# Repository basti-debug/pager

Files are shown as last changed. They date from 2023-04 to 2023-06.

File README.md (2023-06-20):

# pager
A Project which uses LORA Modules to communicate messages over long distances and has simple inputs with buttons and menus. There is also a bluetooth powered companion app for Windows 11

---

This project is not completed, many more features would be possible see:
[not completed features](https://github.com/users/basti-debug/projects/3)

---

Please also visit our wiki for more questions:
[wiki](https://github.com/basti-debug/pager/wiki)



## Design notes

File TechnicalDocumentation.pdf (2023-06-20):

HWE-Übungen 4CHEL | SS 2022-23

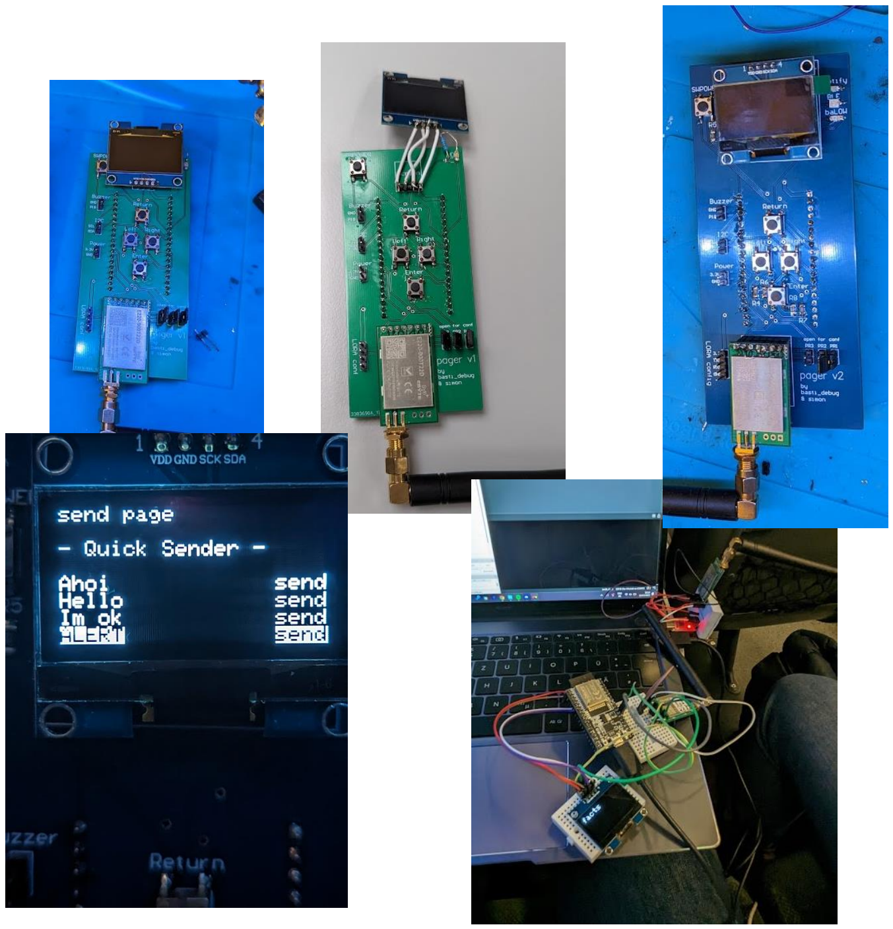
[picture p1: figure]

Pager-Doku-Koller-Mayrhofer | Seite 1 von 9

## Projekt: LoRa - Handlicher Pager

Name Schüler: | Koller Simon, Mayrhofer Sebastian
Betreuer: | Prof. Jena
HTL Rankweil | 4CHEL | Schuljahr 2022-23

Aufgabenbeschreibung:
Aus 2 LoRa Modulen soll ein Projekt unserer Wahl realisiert werden. Es handelt sich dabei um LoRa Module der e220-er Reihe von eByte. Die Kommunikation mit den Modulen verläuft seriell über UART. Die einzige Vorgabe, die wir einzuhalten haben, ist, dass eine Datenübertragung über die LoRa Module im Mittelpunkt des Projektes steht.

Zielsetzung:
Wir haben uns vorgenommen mithilfe der LoRa Module zwei handliche Pager zu realisieren. Dafür wollen wir ein ESP32 DevModule, Screens und Knöpfe verwenden. Als Ziel setzen wir uns mithilfe der Knöpfe zwischen Menüs hin und her zu wechseln und vorgefertigte Nachrichten zu schicken. Das Ganze soll kabellos sein, also Batterie-betrieben. Dennoch wollen wir auch individuelle Nachrichten mittels Laptop oder Handy schicken, damit die Möglichkeiten nicht begrenzt sind. Damit dies immer noch kabellos möglich ist, nehmen wir uns vor den Pager auch über Bluetooth steuerbar zu machen.

Inhaltsverzeichnis:

Liste Entwicklungstools:
Microsoft Word: Version 2210 Greenshot: Version 1.2.10
Altium Designer: Version 23.3.1 Arduino IDE: Version 2.1.0
Git
eByte E220 LoRa Konfigurationstool

Grundkonzept:

Funktionalität:
Schnellnachrichten zwischen den Pagern über Menüs senden oder individuelle Nachrichten über angeschlossene Geräte (z.B. Laptop). Für kurze Strecken können Nachrichten über Bluetooth zwischen Laptop und Pager ausgetauscht werden. Bluetooth kann am Pager im Einstellungsmenü ein- bzw. ausgeschalten werden und der Pager kann vor anderen Bluetooth-Geräten versteckt werden.

Blockdiagramme:

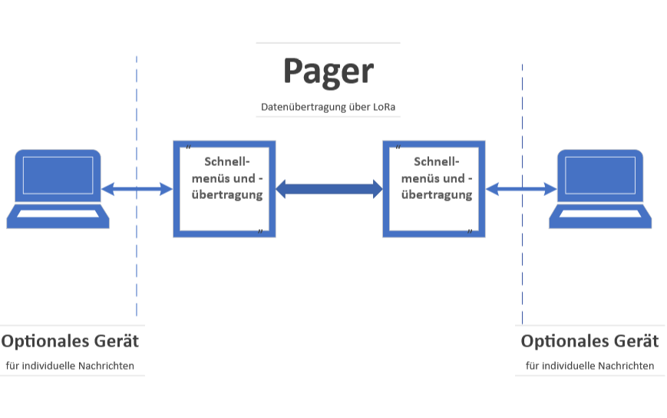
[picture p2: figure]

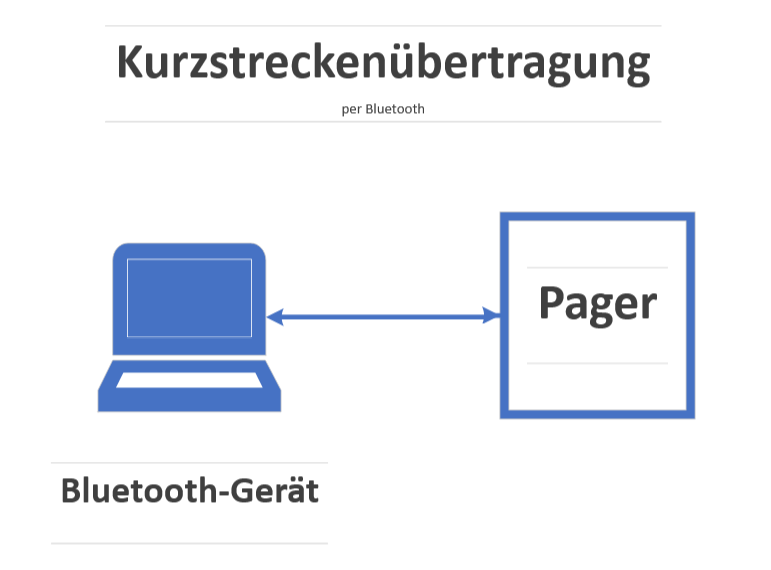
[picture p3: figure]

Technische Realisierung:

LoRa-Modul:

Einführung:
LoRa … Long Range

Als LoRa wird die von Semtech hergestellte Low-Power-Wide-Area-Network-Technology (LPWAN) bezeichnet.

Die großen Vorteile von LoRa sind bereits im Namen ersichtlich: große Reichweite und geringer Energieverbrauch.

Zur Signalübertragung verwendet LoRa die Chirp-Spread-Spectrum-Technologie (CSS). CSS kombiniert 2 Aspekte der Informationstechnik:

- Chirps:
- Spread-Spectrum:

Chirps beschreiben Signale mit zeitlichen Frequenzänderungen, während Spread-Spectrum ein Verfahren ist, bei dem ein Signal gezielt umgewandelt wird, um eine größere Bandbreite und ein breiteres Frequenzspektrum zu nutzen.

Vorteile:

- Geringere Störanfälligkeit
- Hohe Datensicherheit
- Erschwert dritten, übertragene Daten auszulesen

Einstellmöglichkeiten:
Mit der Software von eByte (s.o.) kann das LoRa Modul konfiguriert werden:

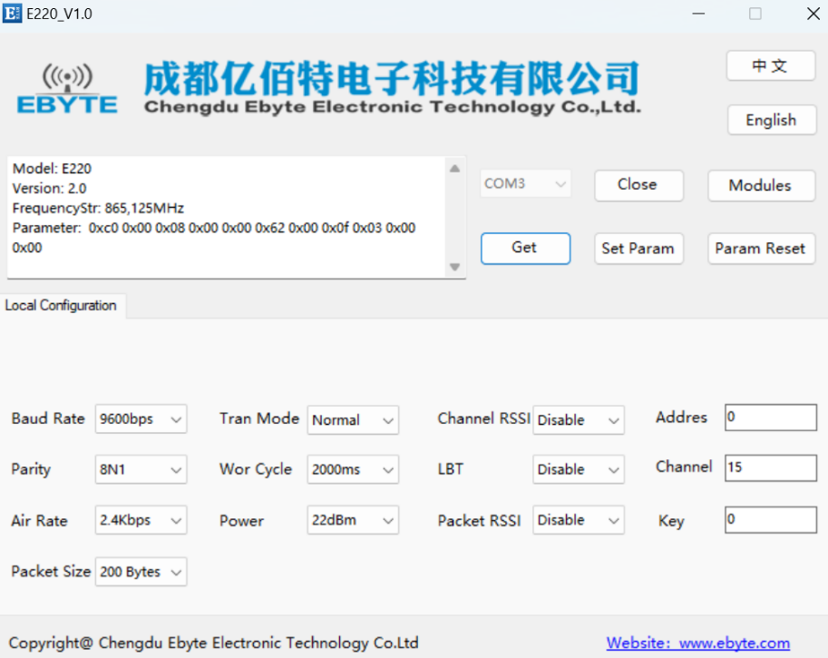
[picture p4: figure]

Die wichtigsten Parameter dabei sind Baud Rate, „Addres“ und Channel. Damit zwei oder mehrere LoRa-Module miteinander kommunizieren können, ist es wichtig, dass diese auf dieselbe Adresse und denselben Channel konfiguriert werden. Die Baud Rate von 9600bps haben wir gewählt damit wir auch einfach mit Terminal Programmen arbeiten können. Die restlichen Parameter können auf den
Standardeinstellungen gelassen werden.

GUI:
Wir verwenden das 1,3 Zoll I2C Display von AZ-Delivery mit einer Auflösung von 128 X 64 Pixel. Der Bildschirm dient als Benutzeroberfläche für den Pager. Hier kann der Benutzer die zuvor empfangenen Nachrichten oder die aktuellen Einstellungen ansehen. Außerdem kann er vorgefertigte Schnellnachrichten auswählen und verschicken. Das Ganze kann in 3 Schnellmenüs erreicht werden:
- Home-Page
- Send page
- Connection settings

Home-Page:
Bild und Beschreibung einfügen.

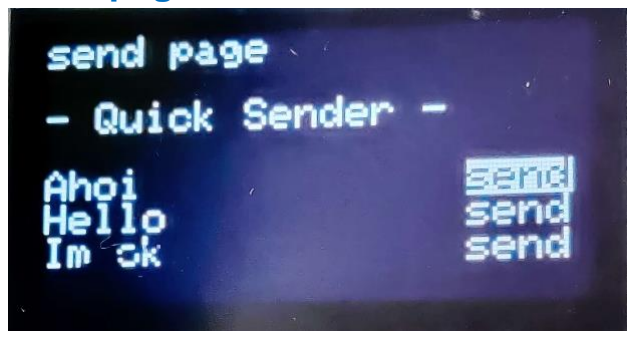
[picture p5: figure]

Send page:
Auf der send-Seite können die Schnellnachrichten ausgewählt und über LoRa versendet werden. Es besteht eine programmierbare Auswahl an Schnellnachrichten.

(Bild: 3 Schnellnachrichten „Ahoi“, „Hello“, „Im ok“. Ersteres ist ausgewählt)

Connection settings:
Hier können Bluetooth-Einstellungen vom Pager verändert werden. Zum einen kann Bluetooth ein- bzw. ausgeschalten werden. Und es kann eingestellt werden, ob der Pager von anderen Bluetooth-Geräten erkannt werden kann.

Außerdem wird in der Info-Anzeige in der unteren Hälfte des Displays der Bluetooth-Name und der Status angezeigt.

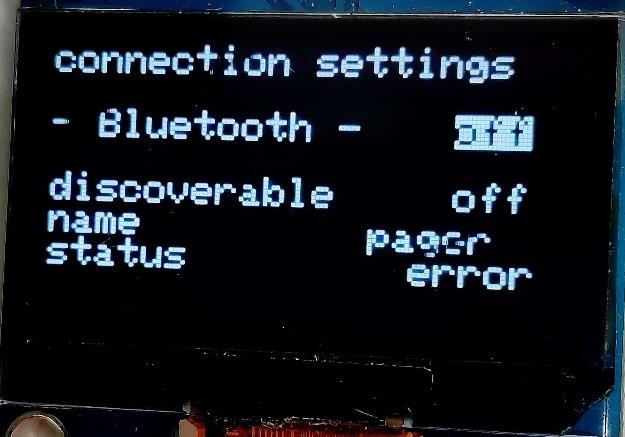
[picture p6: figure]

(Bild: Status = error, weil noch nicht zu Gänze ausprogrammiert).

Erweiterte Anzeigeelemente:
Auf der rechten Seite des Displays gibt es 3 Leds:
- die erste, die Notification LED, war eigentlich vorgesehen, dass diese blinkt sobald eine neue Nachricht ankommt doch wir hatten leider Pins ohne Ausgangstreiber des ESPs geroutet und nun haben wir keinen Pin mehr übrig -> Funktion nicht implementiert
- die zweite, die BLE LED, leuchtet sobald Bluetooth aktiviert ist
- die dritte, die baLOW LED, war anfangs als Batterie Alarm vorgesehen, doch da wir die Batterie direkt in unseren Circuit einspeisen und kein BMS dazwischen ist, können wir nicht herausfinden ob die Batterie voll oder leer ist, wir wissen nur dass sie leer ist wenn der ESP abstürzt -> Daher haben wir diese als ALERT (Alarm) LED umfunktioniert, sie soll nun den Nutzer, zusammen mit dem Buzzer auf eine wichtige Nachricht hinweisen.

Bedienelemente:
Die Menüs werden über 5 Taster bedient. Mit den Taster „Left“ und „Right“ kann zwischen den Menüs gewechselt werden. In welche Richtung ist dabei selbsterklärend. Mit dem unteren Taster („Return“) kann gescrollt werden. Und mit „Enter“ wird die jeweilige Aktion ausgeführt. Z.B.: Bluetooth einschalten oder Schnellnachricht versenden.

Mit dem Taster SWPower können empfangene Nachrichten nach dem Lesen „gelöscht“ werden. Das heißt, die Nachrichten werden aus der Anzeige auf der Home-Page entfernt. Ebenfalls wird durch den SWPOWER eine anstehende Alarm Meldung quittiert.

Akustische Empfangssignalisierung:
Damit Nutzer des Pagers auch auf jeden Fall bemerken, dass sie eine Nachricht empfangen haben, haben wir zusätzlich zur LED, eine akustische Signalisierung über einen Piezo-Buzzer eingebunden. Bei Empfang eines Alarms, der im Quick Send Menu vorhanden ist, wird eine kleine Melodie abgespielt.

Piezo-Buzzer:
Piezo-Buzzer oder Summer basieren auf dem physikalischen Prinzip des inversen Piezo-Effekts. Dabei werden an elektrisch neutralen Kristallen (z.B. Siliziumdioxid SiO2) Spannungen angelegt. Diese angelegten Spannungen sorgen dafür, dass sich der Kristall verformt und so mechanische Schwingungen ausführt. Spannung und mechanische Schwingung sind dabei direkt proportional.

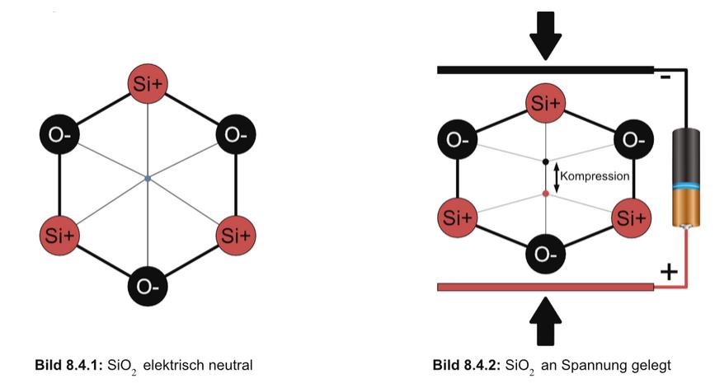
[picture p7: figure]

Schaltet man nun die Spannung mit unterschiedlichen Frequenzen ein und aus entstehen daraus Töne.

Desktop Applikation:
Damit bei der erweiterten Bedienung des Pagers über einen Laptop oder PC keine nervtötende Terminal-Programme und Converter benötigt werden, haben wir eine Steuerung des Pagers über eine Desktop-Applikation kreiert.

Mit dieser ist es Möglich benachrichtigt zu werden wenn eine Nachricht auf dem über Bluetooth verbundenem Pager eingetroffen ist. Ebenfalls war vorgesehen das man die Quick Send Nachrichten abändern kann und z.B. den Namen des Gerätes ändern kann. Dies wurde jedoch aufgrund Zeitlichen Mangels nicht vollständig umgesetzt.

ESP32:
Der ESP32 ist das Herzstück des Pagers. Er verbindet alle Module und steuert diese an. (LoRa, Bildschirm, Taster, Buzzer, LEDs). Wie verwenden das vorgefertigte ESP32 Wrover Module. Features und Funktionalität des Moduls können in dessen Dokumentation nachgelesen werden (siehe Literaturnachweise).

LoRa-Ansteuerung:
Das LoRa Modul benötigt eine Ansteuerung über UART. Die UART-Konfiguration ist dabei, von der vorherigen LoRa-Konfiguration abhängig. Bei uns also 8N1 und eine Baud-Rate von 9600bps.

(UART Dokumentation -> Literaturnachweise)

Screen-Ansteuerung:
Der 1,3“ Screen wird über IIC, mit Hilfe der „Adafruit_GFX“ und der „Adafruit_SH110X“ Library angesteuert.

Ablauf der Erstellung:
Wir starteten mit einem Testaufbau der aus einem LORA Modul und einem UART Converter bestand und einem LORA Modul mit einem ESP. Dieser Testaufbau wurde von uns am Längsten benutzt um die Grundlagen der LORA Module kennenzulernen und die Basis des Codes zu schreiben.

Nach der Fertigstellung der Grundlagen haben wir mit dem Design eines ersten Prototypen gestartet, wobei uns nach kurzem Testen gleich einige Fehler im Design aufgefallen sind, wir hatten ein sehr starkes Tasterprellen, welches durch die internen PullUps des ESPs entstanden. Wir haben anschließend noch einen Fehler begangen der uns später noch einholte, wir haben die Bauteile nicht gesocketed sondern direkt drauf gelötet.

Nach dem wir mit der ersten Version des Boards die Software des Pagers schrieben, haben wir eine zweite Version erstellt in welcher wir unsere Fehler ausglichen.

Gegen Ende finalisierten wir die Software des Pagers selbst und starteten mit der Bluetooth implementation und der Windows Software

Probleme:

LORA Konfiguration
Aufgrund der schlechten Dokumentation unseres LORA Bausteines wussten wir Anfangs nicht wie wir das Board ansteuern sollen oder wie wir den Baustein konfigurieren sollen. Es dauerte einige Zeit bis wir die richtigen Einstellungen getroffen haben und über LORA Daten senden konnten -> mittlerer Zeitverlust

Screens
Aufgrund des mehrfachen Wechsels der Boards sind uns die Bildschirme eingegangen, wir probierten diese wieder und wieder zu reparieren, doch einer bei einer der beiden Screens war das Backlight defekt, welches wir nicht wieder reparieren konnten.

Bluetooth in WinUI3
Gegen Ende des Projektes als wir mit der Windows App starteten, hatten wir massive Probleme, da es uns Anfangs nicht möglich war die Bluetooth API von Windows korrekt anzusteuern, doch als wir ein externes NuGet nahmen, statt der Windows direkten API, funktionierte der Aufbau der Verbindung, jedoch dauert sie ein wenig länger.

Bedienungsanleitung:
Eine Ausgiebige Bedienungsanleitung, inklusive einer Erklärung der Implementation ist unter https://github.com/basti-debug/pager zu finden Code, Software sind ebenfalls in der Github Repository zu finden

Literaturnachweise:
Piezo-Buzzer

https://edistechlab.com/piezo-summer-buzzer/?v=fa868488740a

ESP32 Wrover

https://cdn-shop.adafruit.com/product-files/3384/esp32-wrover_datasheet_en.pdf

UART

https://www.ti.com/lit/ug/sprugp1/sprugp1.pdf?ts=1686988071833&ref_url=https%253A%252F %252Fwww.google.gr%252F (https://www.ti.com/lit/ug/sprugp1/sprugp1.pdf?ts=1686988071833)

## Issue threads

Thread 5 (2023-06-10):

code arduino

basti-debug, 2023-06-10:
- [x] Connection menu (add bluetooth devices)
- [x] main menu
- [x] messages history
- [x] send messages

basti-debug, 2023-06-10:
Done with commit [c74a332](https://github.com/basti-debug/pager/commit/c74a332a60129acd2a4b95ad5af3121f2de137e6)
(Pager Software V4)

basti-debug, 2023-06-10:
```c++
// Send Page
void sendpage(int cursor){
  display.clearDisplay();

  display.setTextSize(1);
  display.setTextColor(SH110X_WHITE);
  display.setCursor(0,0);
  display.println("send page");

  display.println("");
  display.println("- Quick Sender -");
  display.println("");
  display.println(msg1);
  display.println(msg2);
  display.println(msg3);

  if(cursor==1){
    //first message
    display.setCursor(100, 32);
    display.setTextColor(SH110X_BLACK, SH110X_WHITE);
    display.print("send");
    //second entry, second msg
    display.setCursor(100,40);
    display.setTextColor(SH110X_WHITE,SH110X_BLACK);
    display.print("send");
    //third entry, thrid msg
    display.setCursor(100,48);
    display.print("send");
  }

  if (cursor == 2){
    //first message
    display.setCursor(100, 32);
    display.print("send");
    //second entry, second msg
    display.setTextColor(SH110X_BLACK, SH110X_WHITE);
    display.setCursor(100,40);
    display.print("send");
    //third entry, thrid msg
    display.setTextColor(SH110X_WHITE,SH110X_BLACK);
    display.setCursor(100,48);
    display.print("send");
  }

  if (cursor == 3){
     //first message
    display.setCursor(100, 32);
    display.print("send");
    //second entry, second msg
    display.setCursor(100,40);
    display.print("send");
    //third entry, thrid msg
    display.setTextColor(SH110X_BLACK, SH110X_WHITE);
    display.setCursor(100,48);
    display.print("send");
    display.setTextColor(SH110X_WHITE,SH110X_BLACK);
  }

  display.display();
}
```

Closed 2023-06-10.

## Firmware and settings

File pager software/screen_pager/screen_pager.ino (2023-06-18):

/*

  Pager Code v4
  by basti_debug

  This is script is in charge of:
*  handling incomming traffic from the module 
*  displaying:
*  * right menu (activate/deactivate bluetooth)
*  * main menu (see latest message)
*  handling user input

* v3 
* Handling Bluetooth Actions 

* v4
* send menu 
* basic sending possible

* v5 
* fixed send menu 
* added Led support

* v6
* bluetooth handling added

*/


// needed Dependencys

#pragma region Dependencys

#include <Wire.h> // IIC 
// Screen
#include <Adafruit_GFX.h>
#include <Adafruit_SH110X.h>

// Bluetooth

#include "BluetoothSerial.h"

#include "Arduino.h"

#pragma endregion

#pragma region Macros
// Screen Address
#define i2c_address 0x3c

// Screen Dimentions
#define screen_width 128
#define screen_height 64

// Initalisation of the Screen with the Adafruit library
#define oled_reset -1
Adafruit_SH1106G display = Adafruit_SH1106G(screen_width, screen_height, &Wire, oled_reset);

// define pins
#define BUZZER_PIN 18
#define RIGHT_PIN 14
#define ENTER_PIN 27
#define LEFT_PIN 25
#define RETURN_PIN 26 
#define POWER_PIN 33

#define bleLED 4
#define notifyLED 12
#define batterylowLED 12

#define NUMFLAKES 10
#define XPOS 0
#define YPOS 1
#define DELTAY 2
#define MAX_DATA_LENGTH 60

#pragma endregion

#pragma region Global Variables

char receivedData[MAX_DATA_LENGTH];
int dataIndex = 0;
int btdataIndex = 0;


// MACROS

// ! you can change this !  but be aware that corresponding programms may not work anymore 

// Clearance macro 
char res = '%'; // if this is send over the Serial2 connection the current message will be cleared 

// end of message macro 
char end = ';';

// Alert Message Macro 
char alertmacro = '|';

// bluetooth macro
char blmacro = '$';
bool bllora;

char blloopmacro = '~';
bool blloop; 
// BUFFERS

// Input LORA Data Buffer
char data; 

// Bluetooth Buffer
char btdata;
char btMAdata; // macro alert buffer

// Bluetooth forwording buffer
char rrDBuffer[MAX_DATA_LENGTH]; 

// Variable which helps that messages are not send everytime over the Bluetooth line
int comp;

// MELODY FOR NOTIFICATION

int melody[] = {200,200,100,500,500,100,500,200};
int durations[] = {100, 100, 100, 100, 100, 100, 100, 100};




// MENU AREA

// Menu Variables Area
int selectedMenu = 1; // 0 left messages menu, 1 Main Menu , 2 right bluetooth menu

bool bldisco = false;
bool blon = false;
int blstatus = 0; // 0 = error, 1 = connected, 2 = open
String blname = "pager"; //+ random(1,999); // Here you could change the default device name / currently pager with random number 

// Recieve Mark so when true message will be cleared
bool bread;



// Variables needed for settings menu selection
int sc = 1; // cycle
int maxsc = 2;// Number of Entrys ! change if more entrys added ! 
int masxcursor = 4; // Number of Entrys send menu ! change if more entrys in the menu added !


int e1 = 0;
int e2 = 0; 
int e3 = 0;

int cursor = 1;

// Messages 
String msg1 = "Ahoi";
String msg2 = "Hello";
String msg3 = "Im ok";


BluetoothSerial SerialBT;

#pragma endregion

// Functions 

void Snotifcation(){
  // Melody
  int melody[] = {200,200,100,500,500,100,500,200};
  int durations[] = {100, 100, 100, 100, 100, 100, 100, 100};

  for (int i = 0; i < sizeof(melody)/sizeof(int); i++) {
    tone(BUZZER_PIN, melody[i]);
    delay(durations[i]);
    noTone(BUZZER_PIN);
    delay(100);
    }
}

void sendDataLORA(String data){ // send Data over LORA
  Serial2.print(data);
}

void rdLORA(){
    digitalWrite(batterylowLED,HIGH); // Traffic LED for testing 
    data = Serial2.read(); 
    
    if (dataIndex < MAX_DATA_LENGTH ) {
      receivedData[dataIndex] = data;
      dataIndex++;
    } 
    
    digitalWrite(batterylowLED,LOW);
}

void rdBluetooth(){
    btdata = SerialBT.read(); 
    Serial.println(btdata);
    if (btdataIndex < MAX_DATA_LENGTH && isAscii(btdata)) {
      Serial.println(btdata);
      receivedData[btdataIndex] = btdata;
      btdataIndex++;
    } 
}

void blloopfunction(){
  comp = memcmp(rrDBuffer,receivedData,sizeof(rrDBuffer));
  if (comp != 0)
  {
    SerialBT.println(receivedData);
    strcpy(rrDBuffer, receivedData);
  }
}
void overloaddata(){
    if (dataIndex > MAX_DATA_LENGTH || btdataIndex > MAX_DATA_LENGTH || bread == true || data == res || btdata == res) {
      Serial.println("buffer cleared");
      for (int i = 0; i < MAX_DATA_LENGTH; i++) {
        receivedData[i] = 0;
      }
      for(int i = 0; i < MAX_DATA_LENGTH; i++){
        rrDBuffer[i]=0;
      }
      dataIndex = 0;
      bread = false;
      digitalWrite(notifyLED,LOW);
      data = 0;
      delay(10);
    }
}

void handleAlerts(){
  if (data == alertmacro){
    digitalWrite(notifyLED,HIGH);
    for (int i = 0; i < sizeof(melody)/sizeof(int); i++) {
    tone(BUZZER_PIN, melody[i]);
    delay(durations[i]);
    noTone(BUZZER_PIN);
    delay(100);
  }
  }
}

void receive(){    // handling incomming data from the module and writing to the receivedData variable
  overloaddata();
  if (Serial2.available()) { // LORA receive
    rdLORA();
    handleAlerts();
  }
  if (bllora == true){    // Bluetooth receive 
    rdBluetooth();  
  }
  if(blloop == true){
    blloopfunction();
  }
}

// PAGES 

// Display the Main Page, automaticly clears the screen so cant be used when displaying additionally
void mainpage(bool read){
  display.clearDisplay();

  // Heading

  display.setTextSize(1); 
  display.setTextColor(SH110X_WHITE); 
  display.setCursor(0,0);
  display.println("home page");
  display.println("");
  // Info  
  display.println("Last Message:");
  display.println("");
  
  display.println(receivedData);

  

  display.display();
}

// Send Page
void sendpage(int cursor){
  display.clearDisplay();

  display.setTextSize(1); 
  display.setTextColor(SH110X_WHITE); 
  display.setCursor(0,0);
  display.println("send page");

  display.println("");
  display.println("- Quick Sender -");
  display.println("");
  display.println(msg1);
  display.println(msg2);
  display.println(msg3);
  display.setTextColor(SH110X_BLACK, SH110X_WHITE);
  display.println("ALERT");
  display.setTextColor(SH110X_WHITE,SH110X_BLACK);

  if(cursor==1){
    //first message 
    display.setCursor(100, 32);
    display.setTextColor(SH110X_BLACK, SH110X_WHITE);
    display.print("send");
    //second entry, second msg 
    display.setCursor(100,40);
    display.setTextColor(SH110X_WHITE,SH110X_BLACK);
    display.print("send");
    //third entry, thrid msg
    display.setCursor(100,48);
    display.print("send");
    //fourth entry
    display.setCursor(100,56);
    display.print("send");
  } 

  if (cursor == 2){
    //first message 
    display.setCursor(100, 32);
    display.print("send");
    //second entry, second msg
    display.setTextColor(SH110X_BLACK, SH110X_WHITE); 
    display.setCursor(100,40);
    display.print("send");
    //third entry, thrid msg
    display.setTextColor(SH110X_WHITE,SH110X_BLACK);
    display.setCursor(100,48);
    display.print("send");
    //fourth entry
    display.setCursor(100,56);
    display.print("send");
  }

  if (cursor == 3){
     //first message 
    display.setCursor(100, 32);
    display.print("send");
    //second entry, second msg
    display.setCursor(100,40);
    display.print("send");
    //third entry, thrid msg
    display.setTextColor(SH110X_BLACK, SH110X_WHITE); 
    display.setCursor(100,48);
    display.print("send");
    display.setTextColor(SH110X_WHITE,SH110X_BLACK);
    //fourth entry
    display.setCursor(100,56);
    display.print("send");
  }
  if (cursor == 4){
     //first message 
    display.setCursor(100, 32);
    display.print("send");
    //second entry, second msg
    display.setCursor(100,40);
    display.print("send");
    //third entry, thrid msg
    display.setCursor(100,48);
    display.print("send");
    //fourth entry
    display.setTextColor(SH110X_BLACK, SH110X_WHITE); 
    display.setCursor(100,56);
    display.print("send");
    display.setTextColor(SH110X_WHITE,SH110X_BLACK);
  }

  display.display();
}

// Menupage with 4 parameters
// (0-not selected/off, 1-not selected/on, 2-selected/off, 3-selected/on)
// sc == cursor 
// Page also displays name and status of the connection

void menupage(int e1, int e2, int e3, int sc){
  display.clearDisplay();

  display.setTextSize(1); 
  display.setTextColor(SH110X_WHITE); 
  display.setCursor(0,0);
  display.println("connection settings");

  display.println("");
  display.println("- Bluetooth -");
  display.println("");
  display.println("discoverable");
  display.println("name");
  display.println("status");

  // cursor display function

  if(sc==1){
    //first entry, Bluetooth on off toggle
    display.setCursor(100, 16);
    display.setTextColor(SH110X_BLACK,SH110X_WHITE); 
    if(e1==0){
      display.print("off");
    }
    if(e1==1){
      display.print("on");
    }
    display.setTextColor(SH110X_WHITE,SH110X_BLACK);
    
    //second entry, discoverable toggle on off
    display.setCursor(100,32);
    if(e2==0){
      display.print("off");
    }
    if(e2==1){
      display.print("on");
    }

  } 

  if (sc == 2){
    //first entry, Bluetooth on off toggle
    display.setCursor(100, 16);
    if(e1==0){
      display.print("off");
    }
    if(e1==1){
      display.print("on");
    }
    
    //second entry, discoverable toggle on off
    display.setCursor(100,32);
    display.setTextColor(SH110X_BLACK,SH110X_WHITE); 
    if(e2==0){
      display.print("off");
    }
    if(e2==1){
      display.print("on");
    }
    display.setTextColor(SH110X_WHITE,SH110X_BLACK);
  }
  


  // Display the Name
  display.setCursor(80,42);
  display.print(blname);

  // Display Status

  if(blstatus == 0)
  {
    display.setCursor(90,50);
    display.print("error");
  }
  if(blstatus == 1)
  {
    display.setCursor(90,50);
    display.print("connected");
  }
  if(blstatus == 2)
  {
    display.setCursor(90,50);
    display.print("open");
  }
  if(blstatus == 3)
  {
    display.setCursor(90,50);
    display.print("closed");
  }
  display.display();
}




// Setup

void setup() {

  Serial.print(blname);

  // pinmodes

  pinMode(ENTER_PIN, INPUT_PULLUP); // Enter Button
  pinMode(LEFT_PIN, INPUT_PULLUP); // Left Button
  pinMode(RIGHT_PIN, INPUT_PULLUP); // Right Button
  pinMode(RETURN_PIN, INPUT_PULLUP); // Return Button
  pinMode(POWER_PIN, INPUT_PULLUP); // Top Button

  pinMode(bleLED,OUTPUT); //Bluetooth LED
  pinMode(notifyLED, OUTPUT); // Notification LED 
  pinMode(batterylowLED,OUTPUT); // ERROR / Battery LED
  pinMode(BUZZER_PIN,OUTPUT); //Buzzer


  Serial.begin(9600); // Start Serial intern / only TESTING
  Serial2.begin(9600); // Start LORA   

  delay(250);
  display.begin(i2c_address, true);  // initalize Screen

  display.display(); 
  delay(2000);
  Serial.println(blname +" serial online");

}

void loop() {

  receive(); // This Function Handles all the incomming Data, also place of message manipluation
  
 
  // BUTTON Handling

  if(digitalRead(POWER_PIN) == LOW){  // Bread Button so when pressed notification deleted 
    bread = true;
  }

  if (digitalRead(RIGHT_PIN) == LOW) {  // Scroll Right
    if(selectedMenu >2){}
    else{selectedMenu++;}
  }

  if(digitalRead(LEFT_PIN) == LOW){   // Scroll Left
    if(selectedMenu < 0){}
    else{selectedMenu--;}
  }

#pragma region Cycle Button pressed Event

  if(digitalRead(RETURN_PIN) == LOW){ // Cycle through the Settings options
    if(selectedMenu == 2){  // When Settings Menu selected
      sc++;
    }
    if(selectedMenu == 0){  // When in Send Menu
      cursor++;
    }
    
    if(cursor > masxcursor){
      cursor = 1;
    }

    if (sc > maxsc){
      sc = 1;
    }
    delay(25);
  }
#pragma endregion

  // EVENT ENTER
#pragma region ENTER Pressed
  // Event when enter is pressed - so setting is changed 
  if(digitalRead(ENTER_PIN) == LOW){ 
    if(selectedMenu == 2){  // When Settings Menu selected
      switch (sc){ // switch case where cursor is
      case 1: // Cursor position 1 
        e1++;
        if (e1 == 2){e1 = 0;}
      break;
      case 2: // Cursor position 2
        e2 ++;
        if (e2 == 2){e2= 0;}
      break;
    }
    }
    if(selectedMenu == 0){  // When in send Menu
    Serial.print("send");
    Serial.print(cursor);
      switch (cursor)
      {
      case 1:
        sendDataLORA(msg1);
        break;
      case 2:
        sendDataLORA(msg2);
        break;	
      case 3:
        sendDataLORA(msg3);
        break;
      case 4: 
        sendDataLORA(String(alertmacro));
        break;
      default:
        break;
      }
    }
    
    

  }
#pragma endregion
// MENU HANDLING 
#pragma region Menu Area when which Menu is selected which action should be taken
  if(selectedMenu == 0){
    sendpage(cursor);
  }
  if(selectedMenu == 1){
    // MAIN PAGE
    mainpage(bread); 
  }
  if(selectedMenu == 2){
    // SETTINGS PAGE
    
    menupage(e1,e2,e3,sc);
  }

  // Bluetooth Handling
  if (SerialBT.available()) {
    btMAdata = SerialBT.read();
  }

  // Reacting to the bluetooth handler
  if(btMAdata == blmacro){
    Serial.println("Bluetooth to LORA activate");
    bllora = true;
  }

  if(btMAdata == blloopmacro){
    //Serial.println("Internal Bluetooth Forwording from LORA to Bluetooth active");
    blloop = true;
  }
#pragma endregion

#pragma region Bluetooth Handling ON OFF
// BLUETOOTH STATE HANDLER

  if(e1 == 1){ // Bluetooth ON
    SerialBT.begin(blname); // Start Bluetooth service
    digitalWrite(bleLED, HIGH);
    blstatus = 2; 
  }
  if(e1 == 0){ // Bluetooth off
    SerialBT.end();
    digitalWrite(bleLED, LOW);
    blstatus = 3;
  }

#pragma endregion

  delay(100);
}

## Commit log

2023-04-18 added pcb
2023-05-31 added Bluetooth recive function - not working correctly, loosing data
    [screen_pager.ino]
2023-06-16 added led support, buzzer implementation, alters and fixed problems
    [screen_pager.ino]
2023-06-18 added extended Bluetooth support for arduino code, so no endless sending, and notification support(broken) for winui3
    [screen_pager.ino]
2023-06-20 added pcb v2
    [LoRa Pager v2.PrjPcb, LoRa Pager.PrjPcb, lora.SchLib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]
